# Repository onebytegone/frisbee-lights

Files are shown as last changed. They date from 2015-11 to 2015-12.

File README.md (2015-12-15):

# Frisbee Lights

This is a LED bracket that attaches to a frisbee. The goal is to make it possible to play frisbee at night.

### Supplies

  * 1x 3D-printed frame ([assembled.stl](exports/assembled.stl))
  * 2x 5mm LED in color of your choice (4x where needed for < v2.0)
  * 1x Resistor (Might not be needed depending on the LEDs)
  * 1x CR2032 coin cell
  * Wire

## Current version report

v1.1 has lasted for about 2hr of fairly rough play from the frisbee's standpoint that is. This is an improvement over v1.0 which started to have issues after ~45min and failed at about the 2hr mark.

One downside with v1.1, it seems to be heavier than v1.0. It appears to impact the flight of the disc a little more than I would like. Don't have any hard data on this however.

_Update 2015-12-05:_ v1.1 finally failed due to one of the arms braking. This is the same issue that killed v1.0. Possible solutions to this for v1.2 are increase arm thickness, drastically reduce the arm length, or switch to SMD LED's to reduce the arm height profile.

_Update 2015-12-08:_ With v2.0, it is fairly easy to mount the unit using a piece of clear packing tape over the top. It is a little unstable on the side with the battery slot. To fix this, I'm recommending a small tab under the front of the battery slot to assist in mounting. For now, a piece of tape can go into the battery slot to hold that side down.

_Update 2015-12-09:_ Using packing tape, over gaphers tape, seemed like a good idea. It tends to fail easily though. Either the frisbee needs to be prepped better or a different, or just stronger, tape is needed.

_Update 2015-12-15:_ Cleaning the frisbee with rubbing alcohol helps remedy the tape adhesion issue. Some new issues with the battery staying in. A friction fit is no longer very suitable. Adding clips to help keep the battery in place.

## Changelog

  * v2.2 - Improve battery retention
    * Add clips to battery holder sides to keep battery in place.
  * v2.1 - Improve mounting, simplify assembly
    * Increased size of the ground channel to fit 1/6W resistor
    * Add mounting tab on battery opening side
    * Fine tuned various wall thicknesses
  * v2.0 - Trying to eliminate the arm issues and lighten overall weight
    * Reduced the LED count to 2
    * Get rid of the LED arms
  * v1.1 - Adjusted with notes from v1.0
    * Has wider arms, LED supports, and a cutout for the wires to slide in
    * Requires some glue for assembly
    * Arms still tend to break off
  * v1.0 - Initial Design
    * Lasted for about 2hr of ultimate frisbee
    * LEDs tend to bend
    * Assembly is hard due to solder joints in the clip
    * 1 arm was broken off in play

## Licence

This work is licensed under a [Creative Commons Attribution-ShareAlike 4.0 International License](http://creativecommons.org/licenses/by-sa/4.0/)

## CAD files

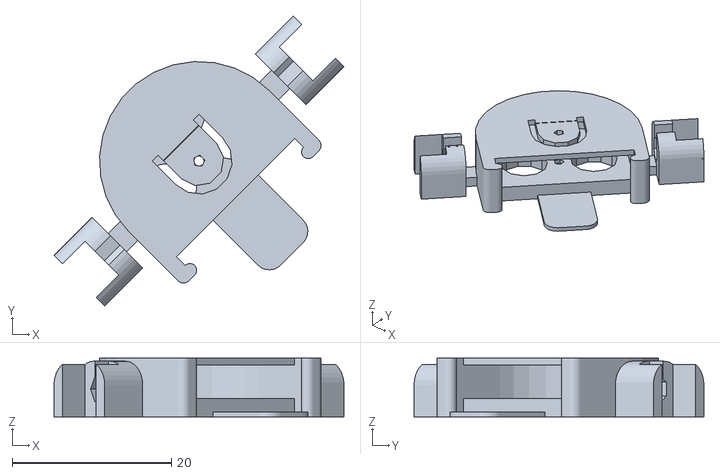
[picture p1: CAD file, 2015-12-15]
exports/assembled.stl
36.4 x 36.4 x 7.40

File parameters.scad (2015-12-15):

/**
 * Created 2015-11-06 by Ethan Smith
 */


/*------------------------
 * HARDWARE
 *----------------------*/

BatteryThickness = 3.2;
BatteryThicknessBuffer = 1;
BatteryDiameter = 21;
BatteryGripSize = 6;

WireChannelDiameter = 4;
LedDiameter = 6;

WireDiameter = 1.5;


/*------------------------
 * FIXED MODEL SIZES
 *----------------------*/

ArmThickness = 1.5;
ArmWidth = 3.2;

LedSupportWallThickness = 1.5;
LedSupportWallLength = 4;
LedClipThickness = 2.75;
LedClipTopWall = 1.5;
LedClipCorner = 3;

MountingArmWidth = 8;
MountingArmLength = 10;
MountingArmThickness = 0.6;
MountingArmCorner = 2;

WireChannelLip = 0.8;
WireChannelDepth = 2;

GroundChannelHeight = 1.8;
GroundChannelWidth = 3;

BatteryHolderWallThickess = 2;
BatteryHolderFace = 0.85;
BatteryHolderLowerFaceMin = 0.55;

BatteryClipNubSize = 1.7;
BatteryClipNubShift = 2.4;
BatteryClipCorner = 1;
BatteryClipWallThickess = BatteryHolderWallThickess;

Overlap = 0.1;


/*------------------------
 * CALCULATED
 *----------------------*/

LedClipWidth = LedSupportWallThickness * 2 + LedDiameter;
LedClipHeight = ArmThickness + WireChannelDiameter + LedClipTopWall;
WireChannelCutout = WireChannelDiameter - WireChannelLip * 2;

BatteryCutoutThickness = BatteryThickness + BatteryThicknessBuffer;
BatteryHolderWidth = BatteryHolderWallThickess * 2 + BatteryDiameter;

TotalArmSpan = WireChannelDepth * 2 + BatteryHolderWidth;

BatteryHolderBaseThickness = GroundChannelHeight + BatteryHolderLowerFaceMin;
BatteryHolderThickness = BatteryHolderBaseThickness + BatteryHolderFace + BatteryCutoutThickness;

BatteryClipLength = BatteryClipNubShift + BatteryClipNubSize/2;
BatteryClipHeight = BatteryHolderThickness;

LightenHoleDiameter = BatteryDiameter/3;
LightenHoleOffset = BatteryDiameter/4;

MountingArmTotalLength = MountingArmLength + BatteryHolderWidth/2 - BatteryGripSize;

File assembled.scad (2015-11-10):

use <elements/main_frame.scad>;
include <parameters.scad>;

main_frame();

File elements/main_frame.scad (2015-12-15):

include <../parameters.scad>;
include <../thirdparty/CornerCutout.scad>;

module main_frame() {
   rotate([0,0,45]) {
      difference() {
         union() {
            batteryHolder();
            rotate([0,0,90]) arm();
            mountingTab();
         }
         translate([-GroundChannelWidth/2,0,-Overlap]) cube([GroundChannelWidth, BatteryHolderWidth/2 + Overlap, GroundChannelHeight + Overlap]);
         translate([0,0,-Overlap]) cylinder(BatteryHolderBaseThickness + Overlap * 2, WireDiameter/2, WireDiameter/2);

         translate([-LightenHoleOffset,0,-Overlap]) cylinder(BatteryHolderBaseThickness + Overlap * 2, LightenHoleDiameter/2, LightenHoleDiameter/2);
         translate([LightenHoleOffset,0,-Overlap]) cylinder(BatteryHolderBaseThickness + Overlap * 2, LightenHoleDiameter/2, LightenHoleDiameter/2);
      }
      translate([-BatteryHolderWidth/2, -BatteryHolderWidth/2 + BatteryGripSize]) batteryClip();
      mirror([1,0]) translate([-BatteryHolderWidth/2, -BatteryHolderWidth/2 + BatteryGripSize]) batteryClip();
   }
}

module mountingTab() {
   halfWidth = MountingArmWidth/2;
   translate([0, -MountingArmTotalLength]) difference() {
      translate([-halfWidth, 0]) cube([MountingArmWidth, MountingArmTotalLength, MountingArmThickness]);

      translate([halfWidth, 0]) CornerCutout(CORNER_SE, MountingArmThickness, MountingArmCorner);
      translate([-halfWidth, 0]) CornerCutout(CORNER_SW, MountingArmThickness, MountingArmCorner);
   }
}

module batteryClip() {
   translate([BatteryHolderWallThickess - BatteryClipWallThickess, -BatteryClipLength]) {
      difference() {
         union() {
            cube([BatteryClipWallThickess, BatteryClipLength + Overlap, BatteryClipHeight]);
            translate([BatteryClipWallThickess, BatteryClipNubSize/2]) cylinder(BatteryClipHeight, BatteryClipNubSize/2, BatteryClipNubSize/2, $fn = 20);
         }
         CornerCutout(CORNER_SW, BatteryClipHeight, BatteryClipCorner);
      }
   }
}

module arm() {
   translate([-ArmWidth/2, -TotalArmSpan/2]) cube([ArmWidth, TotalArmSpan, ArmThickness]);
   rotate([0,0,180])  translate([0, TotalArmSpan/2]) ledClip();
   translate([0, TotalArmSpan/2]) ledClip();
}

module ledClip() {
   difference() {
      totalLength = LedClipThickness + LedSupportWallLength;
      translate([-LedClipWidth/2, 0]) cube([LedClipWidth,  totalLength, LedClipHeight]);
      translate([LedClipWidth/2, 0, LedClipHeight]) rotate([-90,0]) CornerCutout(CORNER_SE, totalLength, LedClipCorner);
      translate([-LedClipWidth/2, 0, LedClipHeight]) rotate([-90,0]) CornerCutout(CORNER_SW, totalLength, LedClipCorner);
      translate([0, -Overlap, ArmThickness + WireChannelDiameter/2]) rotate([-90, 0]) cylinder(h = LedClipThickness + Overlap * 2, r = WireChannelDiameter/2);
      translate([-WireChannelCutout/2, -Overlap, ArmThickness + WireChannelDiameter/2]) cube([WireChannelCutout, LedClipThickness + Overlap * 2, LedClipHeight/2 + Overlap]);
      translate([-LedDiameter/2, LedClipThickness, -Overlap]) cube([LedDiameter, LedSupportWallLength + Overlap, LedClipHeight + Overlap * 2]);
   }
}

module batteryHolder() {
   difference() {
      batteryHolderShape(BatteryHolderWidth, BatteryGripSize, BatteryHolderThickness);
      translate([0,0,BatteryHolderBaseThickness]) batteryHolderShape(BatteryDiameter, 0, BatteryCutoutThickness, BatteryHolderWallThickess + Overlap);
      translate([0,0,BatteryHolderThickness - BatteryHolderFace - Overlap]) rotate([0,0,180]) batteryHolderShape(BatteryHolderWidth/3, 0, BatteryHolderFace + Overlap * 2);
      translate([-BatteryDiameter/6, -BatteryHolderWidth/2 - Overlap, BatteryHolderBaseThickness]) cube([BatteryDiameter/3, BatteryHolderWidth + Overlap * 2, BatteryCutoutThickness]);
   }

   translate([0,0,BatteryHolderThickness - BatteryHolderFace]) rotate([0,0,180]) difference() {
      batteryHolderShape(BatteryHolderWidth/4, 0, BatteryHolderFace, BatteryHolderWidth/5);
      translate([0, 0, -Overlap]) cylinder(BatteryHolderFace + Overlap * 2, WireDiameter/2, WireDiameter/2);
   }
}

module batteryHolderShape(size = 10, grip = 0, thickness = 3, extra = 0) {
   difference() {
      union() {
         translate([-size/2, -size/2 - extra, 0]) cube([size, size/2 + extra, thickness]);
         cylinder(thickness, size/2, size/2);
      }
      translate([-size/2 - Overlap, -size/2 - Overlap, -Overlap]) cube([size + Overlap * 2, grip + Overlap, thickness + Overlap * 2]);
   }

}

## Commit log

2015-11-10 Build v1
    [assembled.scad, main_frame.scad, parameters.scad]
2015-11-10 Exported v1.0
    [assembled.stl]
2015-11-10 Increased arm width
    [parameters.scad]
2015-11-10 Add channel and LED supports
    [main_frame.scad, parameters.scad]
2015-11-10 Exported v1.1
    [assembled.stl]
2015-11-21 Added current version report
2015-12-07 Reduced number of and shortened arms
    [main_frame.scad, parameters.scad]
2015-12-07 Exported shortened arm version
    [assembled.stl]
2015-12-08 Add ground wire channel
    [main_frame.scad, parameters.scad]
2015-12-08 Reduce LED support thicknesses
    [parameters.scad]
2015-12-08 Add lightening holes
    [main_frame.scad, parameters.scad]
2015-12-08 Add model for v2.0
    [assembled.stl]
2015-12-08 v2.0 mounting notes
2015-12-08 Increase side of ground channel to accommodate a 1/6W resistor
    [parameters.scad]
2015-12-08 Reduce LED support distance
    [parameters.scad]
2015-12-08 Updated LED count
2015-12-10 Add mounting tab
    [main_frame.scad, parameters.scad]
2015-12-10 Fine tune face sizing
    [parameters.scad]
2015-12-10 Reduce clip backing size
    [parameters.scad]
2015-12-10 Export assembled STL for v2.1
    [assembled.stl]
2015-12-15 Add battery clip arms
    [main_frame.scad, parameters.scad]
2015-12-15 Export for v2.2
    [assembled.stl]
